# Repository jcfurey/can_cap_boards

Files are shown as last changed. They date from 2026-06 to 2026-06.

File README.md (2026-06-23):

# can_cap_boards

A repo to contain different PCBs with associated gerber files and SPICE sim docs.

The theme: small interior-mount boards that retire vintage multi-section
twist-lock "can" electrolytics in tube amps, replacing them with discrete,
individually serviceable modern radial caps.

> ⚠️ These boards carry **lethal B+ voltages** (400 V+). Discharge and meter
> every section to zero before handling. See each board's README.

## Boards

| Board | Amp | What it replaces | Status |
|---|-----|---|---|
| [`princeton_reverb_aa1164`](princeton_reverb_aa1164/) | Fender Princeton Reverb (AA1164) | 4-section can → 47/22/22/33 µF | design + BOM + SPICE + KiCad project (DRC-clean starter) + gerbers |

Each board folder contains its own `README.md` (design notes), `BOM.md`, an
illustrated `design_reference.html` (schematic + mechanical drawings), a `sim/`
directory with the SPICE supply model, and a `kicad/` directory with the KiCad
sources and `kicad/fab/` fabrication outputs (gerbers, drill, BOM, position).

## License

Apache-2.0 (see [`LICENSE`](LICENSE)).

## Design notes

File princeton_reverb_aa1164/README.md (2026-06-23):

# Princeton Reverb (AA1164) — Filter Cap Board

Interior-mount filter board that retires the original 4-section twist-lock "can"
electrolytic in the blackface Fender Princeton Reverb (AA1164) and close clones,
replacing it with discrete, individually serviceable, modern radial electrolytics.

Mounts inside the chassis among the existing circuitry, with the wire-entry holes
on the edge facing the fiber/eyelet board so the existing B+ wiring lands straight
across. The empty can knockout is covered separately (blanking plate / plug).

> 📄 **Illustrated design reference:** [`design_reference.html`](design_reference.html)
> — a single self-contained page with the schematic, board/mechanical drawings,
> 2-layer stackup, full BOM, and the design rules (R1–R6) as inline SVG. Open it
> in a browser; this README is the plain-text mirror.

> ⚠️ **High voltage.** B+ on the reservoir node sits near **420 VDC** in operation,
> and downstream nodes float up toward it during warm-up. Treat the whole board as
> lethal. Discharge and meter every section to zero before handling.

## Design goals

- Electrical drop-in for the stock can, but with individually replaceable caps
- Modern, high-quality radial electrolytics, **≥ 500 V**
- **Split** power / preamp-reverb grounds for low hum, star-tied
- Existing B+ wiring lands on the fiber-board-facing edge

## Filter values

| Node | Function | Value | Rating |
|---|---|---:|---|
| A (B+1) | Reservoir — 6V6 plates | 47 µF | 500 V, 105 °C |
| B (B+2) | Screens | 22 µF | 500 V, 105 °C |
| C (B+3) | PI / reverb driver | 22 µF | 500 V, 105 °C |
| D (B+4) | Preamp / reverb recovery | 33 µF | 500 V, 105 °C |

Anchor part: **Nichicon UCY2H470MHD** (47 µF / 500 V / 105 °C, 7.5 mm pitch,
16 × 40 mm). The 22 µF and 33 µF come from the same UCY family — confirm the exact
case suffix/size at the distributor.

Notes:
- Node A reservoir bumped to **47 µF** to firm up the low end (stays under the
  GZ34's ~60 µF input-cap limit).
- Node D laid out to accept up to **47 µF** so it stays retunable with an iron.
- Screens (B) and PI/reverb-driver (C) kept at stock 22 µF — extra capacitance
  there buys nothing audible.

## Grounding — split, star-tied

- **GND-PWR** — dirty returns: caps **A + B** and the bleeder
- **GND-PRE** — clean returns: caps **C + D**
- The two pours meet **only** at a single **star link (JP1)**, which is the single
  chassis tie.
  - Fit JP1 → one ground wire, single-point tie.
  - Omit JP1 → run GND-PWR and GND-PRE to their own amp ground buses for a true
    dual return.
- The rectifier center-tap belongs on the **power** side at the star, never on the
  preamp pour.
- Exactly **one** chassis connection either way — no loops.

If the reverb driver (node C) ever injects buzz, moving just that negative from
GND-PRE to GND-PWR turns this into a 3-way split — it's only a pour assignment.

## Layers & routing (2-layer)

- **Fiber-board face:** B+ traces + wire-entry pads. Traces **~2.5 mm** wide
  (robustness / HV margin, not current); teardrop the pad junctions.
- **Far face:** the two ground pours (GND-PWR / GND-PRE), each pulled back
  **≥ 2.5 mm** from B+.
- Same-layer clearance **≥ 2.5 mm** (3 mm where room allows). Opposite-layer
  isolation through 1.6 mm FR-4 is ample at ~420 V; optionally clear the pour in
  the shadow directly under B+ traces.

### KiCad tips

- GND-PWR and GND-PRE are **separate nets** joined by a **net-tie footprint** at
  JP1 — otherwise DRC flags them as a short.
- Put the four B+ nets in their own **net class** (clearance 2.5 mm, track ~2.5 mm)
  so DRC enforces creepage automatically.

## Mechanical

- Rectangular, ~**55–60 × 48 mm**, FR-4 2-layer, 1.6 mm, **1 oz** copper.
- Caps stand off the far face into open interior — verify ~40 mm depth clearance
  for the 47 µF (or lay caps down if it's tight).
- Mount on standoffs; **both mount holes isolated** from copper (or make exactly
  one the ground tie) to avoid a ground loop.

## Bleeder

2 × 100 kΩ 2 W (each ≥ 350 V working) in series (= 200 kΩ) across node A,
returning to GND-PWR. Dissipates ~0.9 W total (~0.45 W each), split across the
two so neither is stressed. Drains node A at power-off; downstream nodes drain
through the amp's dropping resistors while the board is connected. **Always meter
every section to zero before servicing.** Add a bleeder per node if you want each
section to self-drain when the board is pulled.

## Serviceability

- Existing B+ wires solder into labeled wire-entry pads — leave a little slack so
  the board lifts clear when you desolder.
- Silkscreen node labels (A/B+1 … D/B+4), values, and **polarity** at every pad.
- Want tool-free removal later? Add FASTON tabs in parallel with the wire pads.

## Fabrication

- Within both **JLCPCB** and **OSH Park** 2-layer design rules (the ≥ 2.5 mm
  spacing dwarfs their ~0.15 mm minimum; 1.6 mm wire-entry holes are routine).
- 1 oz copper is standard at both (meets the ≥ ½ oz target); 2 oz buys little here.
- OSH Park prices by area (~$5/in², 3 pcs, US-made ENIG) — keep it ~50 mm. Skip
  its 2 oz option: that's a thinner 0.8 mm board, and you want 1.6 mm rigidity.
- JLCPCB is a flat tier (5 pcs) up to 100 × 100 mm, so size is effectively free.
- If you ever convert to **solid-state rectification**, add inrush limiting
  (series resistance / soft-start) — 47 µF hits the PT harder on a cold start
  than the GZ34 does.

## Bill of materials

See [`BOM.md`](BOM.md) — the four filter caps, the bleeder, and the ground star
link (the inter-node dropping resistors stay on the amp's eyelet board).

## Simulation

ngspice model of the AA1164 supply (GZ34 + dropping network) lives in
[`sim/`](sim/) — see [`sim/README.md`](sim/README.md). It confirms the
47/22/22/33 µF set:

| Node | DC (idle) | Ripple (idle) | DC (full output) |
|---|---:|---:|---:|
| A (reservoir) | 420.7 V | 8.0 V pp | 403.5 V |
| B (screens) | 405.7 V | 0.41 V pp | 384.5 V |
| C (PI/reverb) | 358.7 V | 5.1 mV pp | 337.5 V |
| D (preamp) | 318.7 V | 0.1 mV pp | 297.5 V |

Node A sits at ~420 V as designed, the larger reservoir roughly thirds the
stock ripple, the hum-sensitive preamp nodes are filtered to ≤ mV, and the GZ34
sags node A ~17 V at full output (the expected blackface "compression").

## KiCad project

A KiCad 7 project lives in [`kicad/`](kicad/) — see [`kicad/README.md`](kicad/README.md).
Schematic + 2-layer board, **ERC/DRC-clean (0 errors)**, with the split-ground
star-tie and 2.5 mm HV creepage encoded as rules. Fabrication outputs (Gerbers,
drill, BOM, position) are in [`kicad/fab/`](kicad/fab/).

> These are an auto-generated **starting point**: electrically complete and
> rule-clean, but placement/mechanical fit must be verified in the GUI before
> fabbing (board outline, wire-entry positions vs your chassis, exact cap cases).

## Status

- [x] Electrical design (rev F)
- [x] Bill of materials
- [x] SPICE supply sim
- [x] KiCad schematic (ERC-clean)
- [x] KiCad layout (DRC-clean starter — refine mechanical fit in GUI)
- [x] Fabrication outputs (gerbers) — starter set, re-export after refining
- [ ] Built & tested

## License

Apache-2.0 (see repository `LICENSE`).

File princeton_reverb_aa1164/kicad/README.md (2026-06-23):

# KiCad project — AA1164 Filter Cap Board

KiCad 7 project for the Princeton Reverb (AA1164) filter-cap board. This is a
**starting point**: electrically complete, ERC/DRC-clean, with the HV creepage
and split-ground rules baked in — but the placement and mechanical fit still
want a pass in the GUI before you fab it.

> Built/validated with KiCad **7.0.11**. KiCad 9 opens it fine (it will offer to
> upgrade the files). The two generator scripts below are the scaffolding used
> to create it; the `.kicad_sch` / `.kicad_pcb` are now the editable sources.

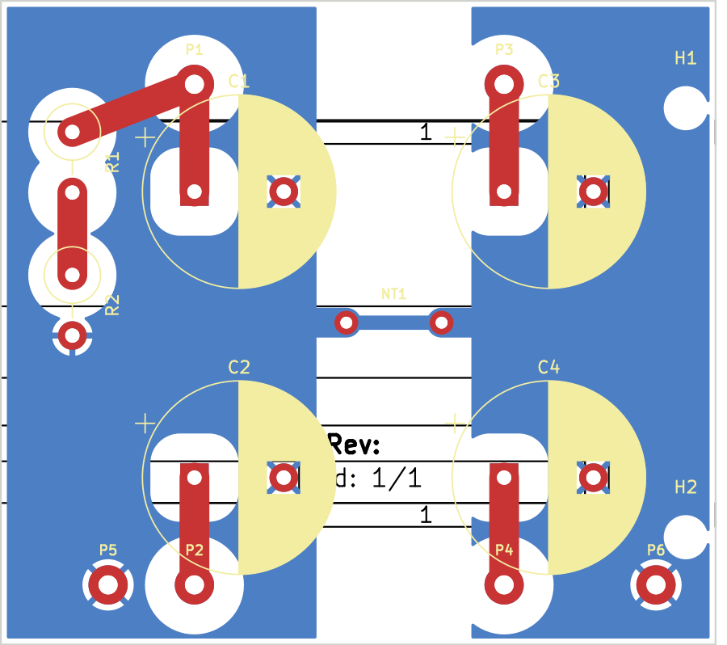
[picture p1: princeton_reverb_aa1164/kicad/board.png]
board


*B.Cu split ground pours (blue) joined only at the NT1 star-tie; F.Cu B+ traces
(red); 2×2 caps with each B+ wire-entry beside its cap; bleeder R1/R2 top-left;
mounting holes right. The wide white rings are the 2.5 mm HV anti-pads in the
pour.*

## Files

| File | What |
|---|---|
| `princeton_reverb_aa1164.kicad_pro` | Project (net classes: 2.5 mm clearance / 2.5 mm tracks) |
| `princeton_reverb_aa1164.kicad_sch` | Schematic — 4 caps, bleeder, 6 wire-entry pads, star-tie, 2 mounts |
| `princeton_reverb_aa1164.kicad_pcb` | 2-layer board: B+ on F.Cu, split GND pours on B.Cu |
| `wire_entry.pretty/` | Custom footprints: `WireEntry_BPlus`, `WireEntry_GND` (1.6 mm hole / 3.3 mm pad), `StarTie_8mm` (net-tie) |
| `fp-lib-table` / `sym-lib-table` | Register the project footprint library |
| `generate_sch.py` / `generate_pcb.py` | The scripts that generated the above (kiutils + pcbnew) |
| `fab/` | Fabrication outputs — see `fab/` |
| `drc.rpt` | Saved DRC run (0 errors) |

## Nets & rules

- B+ nodes are **separate nets** `HV_A..HV_D` (each = wire-entry pad + cap "+",
  plus the bleeder on A) — they only join *outside* the board, in the amp.
- `BLEED_MID` is the junction of the two series bleeder resistors.
- Grounds are **two nets** `GND-PWR` (caps A·B + bleeder) and `GND-PRE`
  (caps C·D), joined **only** at the `NT1` star-tie (a net-tie footprint, so DRC
  permits the single intentional short). Omit/DNP NT1 to run dual returns.
- Board-wide clearance is **2.5 mm** and default track width **2.5 mm** — every
  net here is HV or ground, so one rule enforces the creepage spec everywhere.

## Validation

- **Connectivity** verified by netlist export (matches the intended net map).
- **DRC: 0 errors.** The 12 remaining items are warnings only:
  - `lib_footprint_issues` (8) — headless DRC has no global footprint-library
    table; these disappear in the GUI.
  - `silk_over_copper` (4) — cosmetic cap-outline silk over mask openings.
- KiCad 7's `kicad-cli` has no `erc`/`drc` subcommand (KiCad 8+), so ERC/DRC were
  run via the netlist export and `pcbnew.WriteDRCReport`. **Re-run ERC and DRC in
  your GUI** as a final check after any edits.

## Refine before fabbing

This was placed/routed *blind to the real chassis*. In the GUI:

1. **Verify mechanical fit** — board outline (~60 × 54 mm here vs the ~55–60 × 48
   target), the wire-entry positions against your fiber board, and cap body
   height clearance into the interior.
2. Optionally **regroup the wire-entry pads into one edge row** (they're placed
   next to each cap here for short, clean B+ traces).
3. Confirm the **cap footprints** — all four use `CP_Radial_D16.0mm_P7.50mm`
   (sized for the 47 µF); the 22/33 µF bodies are smaller, so swap to the right
   case once you pick exact parts.
4. Confirm the **bleeder** uses a vertical 2 W footprint that matches your
   resistors, and that the **star-tie** location suits your single chassis tie.
5. Re-run ERC + DRC.

## Regenerating

```sh
pip install kiutils
python3 generate_sch.py      # writes the .kicad_sch
python3 generate_pcb.py      # writes the .kicad_pcb, fills zones, runs DRC
```
Regenerating overwrites GUI edits — once you start editing in KiCad, treat the
`.kicad_sch`/`.kicad_pcb` as the sources and retire the scripts.

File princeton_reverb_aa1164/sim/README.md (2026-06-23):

# AA1164 Power-Supply SPICE Sim

ngspice model of the blackface Princeton Reverb (AA1164) high-voltage supply,
used to verify **ripple at each B+ node** and **DC sag** with this board's
filter set (A/B/C/D = **47 / 22 / 22 / 33 µF**) feeding the stock dropping
network.

## Files

| File | Purpose |
|---|---|
| `aa1164_psu.cir` | ngspice deck — rectifier + filter chain + loads, with a `.control` block that prints DC and ripple per node |
| `plot_ripple.py` | Runs the deck and renders `aa1164_psu_ripple.png` (steady-state ripple per node) |
| `aa1164_psu_ripple.png` | Committed plot of the idle-load result |
| `results.txt` | Saved console output of the idle-load run |

The raw transient dump (`aa1164_psu_nodes.dat`, ~30 MB) is regenerated on every
run and is **git-ignored** — don't commit it.

## Running

```sh
ngspice -b aa1164_psu.cir        # prints the DC/ripple table
python3 plot_ripple.py           # regenerates aa1164_psu_ripple.png
```

Requires `ngspice`, plus `numpy` + `matplotlib` for the plot.

## Circuit model

```
   330-0-330 VAC          GZ34 (2 plates)
   centre-tapped     ┌──►|──┐
   secondary    ─────┤      ├──┬─── A ──[1k]── B ──[4.7k]── C ──[10k]── D
   (CT = gnd)   ─────┤      │  │       │            │            │       │
                     └──►|──┘ 47µF   22µF         22µF         33µF    (each
                               │       │            │            │      to gnd)
                             200k      ▼            ▼            ▼       ▼
                            bleeder  screens   PI/reverb     preamp /
                                     (6V6)      driver      reverb recov
                       6V6 plates ◄──┘
```

- **Rectifier:** GZ34/5AR4 full-wave centre-tap, approximated by a solid-state
  diode with series resistance (`RS=60` in the `.model` + 75 Ω winding R per
  half). This reproduces forward drop and **sag** well, but **not** the GZ34's
  slow indirectly-heated warm-up — that's deliberate; we want steady-state
  numbers, not the turn-on transient (which is exactly why a tube rectifier is
  used: it spares the caps the cold-start surge).
- **Loads** are modelled as DC current sinks per node (tubes ≈ constant-current
  over a line cycle). Idle defaults: A 45 mA, B 5 mA, C 6 mA, D 4 mA (~60 mA
  HT total, typical for a Princeton Reverb).
- **Settling:** the deck runs to **8 s**. The downstream RC poles are slow
  (node D ≈ `RCD·CD` = 10 k × 33 µF ≈ 0.33 s); shorter runs leave the chain
  un-settled and report bogus DC/ripple on C and D. Ripple is measured over the
  last 50 ms (6 × 120 Hz cycles).

> Component values are the **standard AA1164** schematic values (PT secondary,
> dropping resistors, loads). Verify against *your* chassis before trusting the
> absolute volts — especially the transformer secondary, which varies with mains
> voltage and PT model. The **ripple** conclusions are robust to small value
> errors; the **DC** levels scale with whatever your secondary actually is.

## Results

### Idle (~60 mA HT) — the committed plot

| Node | Cap | DC (V) | Ripple (pk-pk) |
|---|-----|---:|---:|
| A — reservoir / 6V6 plates | 47 µF | **420.7** | **8.0 V** |
| B — screens | 22 µF | 405.7 | 0.41 V |
| C — PI / reverb driver | 22 µF | 358.7 | 5.1 mV |
| D — preamp / reverb recovery | 33 µF | 318.7 | 0.1 mV |

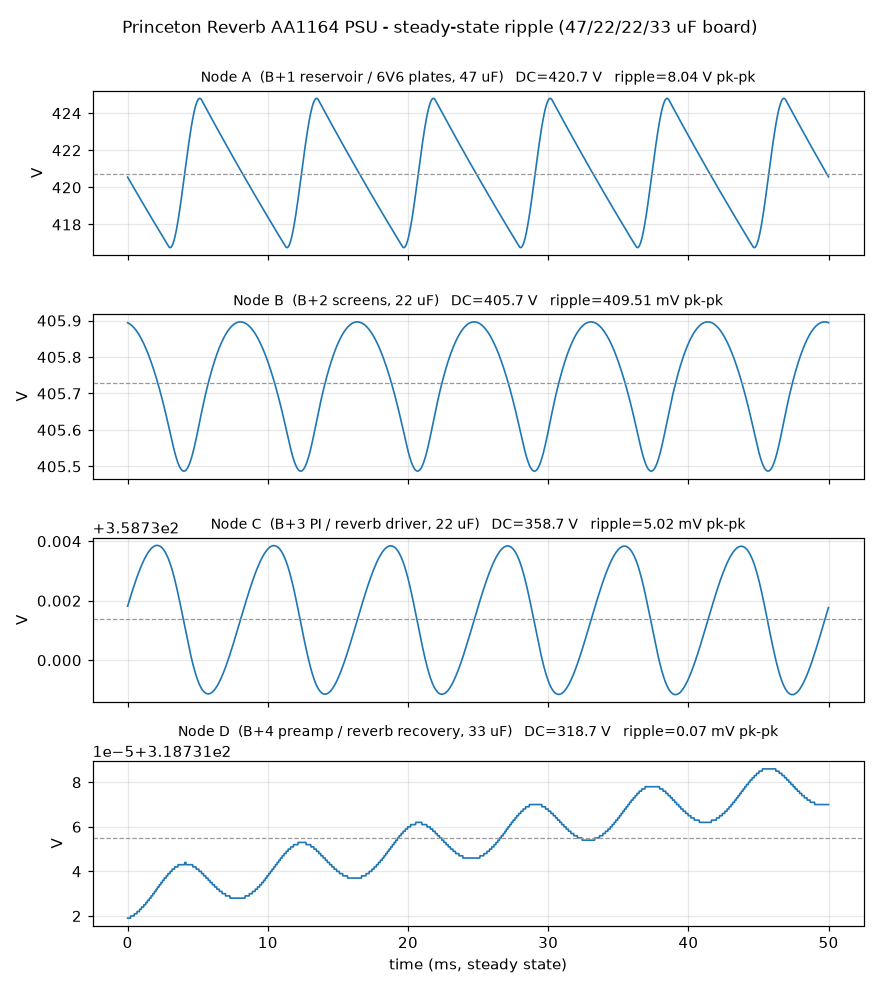
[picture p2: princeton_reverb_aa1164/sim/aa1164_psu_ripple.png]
ripple


### Full output (plates ~80 mA, screens ~9 mA) — sag

| Node | DC (V) | Δ vs idle | Ripple (pk-pk) |
|---|---:|---:|---:|
| A | 403.5 | −17 V | 12.3 V |
| B | 384.5 | −21 V | 0.63 V |
| C | 337.5 | −21 V | 7.9 mV |
| D | 297.5 | −21 V | 0.1 mV |

Reproduce by editing the `.param IA`/`IB` lines near the bottom of the deck.

## What it tells us

- **Node A ≈ 420 V idle**, matching the README's "near 420 V" — the board and
  bleeder rating margin (500 V caps, 200 kΩ bleeder) are correct.
- **Reservoir ripple ~8 V at idle, ~12 V at full output.** That's normal for a
  Princeton-class amp; bumping A from the stock 16 µF to **47 µF** roughly thirds
  the reservoir ripple versus stock, firming the low end.
- **Hum-sensitive nodes are quiet:** screens already at 0.4 V, and the
  PI/preamp nodes (C, D) are filtered to **single-digit mV or below** — well
  under the threshold for audible hum at the preamp.
- **Sag:** node A drops ~17 V plate-to-idle under full output — the GZ34
  "compression" that gives these amps their feel. The larger reservoir trades a
  little of that softness for tighter lows; if you want more sag, that's the
  knob (reservoir µF), not the downstream caps.
- Downstream cap values (B/C/D) buy **no audible ripple improvement** beyond
  stock — consistent with keeping B and C at 22 µF; D's 33 µF is for headroom/
  retunability, not hum.

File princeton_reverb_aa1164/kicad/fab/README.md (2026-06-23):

# Fabrication outputs — AA1164 Filter Cap Board

Generated from `../princeton_reverb_aa1164.kicad_pcb` with `kicad-cli` (KiCad 7).
**Regenerated artifacts** — re-export after any board edit.

> ⚠️ This is a *starting* layout — verify mechanical fit and re-run DRC in the
> KiCad GUI before actually ordering. See `../README.md`.

## Contents

| File | What |
|---|---|
| `princeton_reverb_aa1164-gerbers.zip` | All Gerbers + drill, zipped for upload |
| `gerbers/*.gbr` | RS-274X Gerbers (F.Cu, B.Cu, F/B silkscreen, F/B mask, Edge.Cuts) |
| `gerbers/*.drl` | Excellon drill (absolute origin, mm) + `-drl_map.gbr` map |
| `gerbers/*.gbrjob` | Gerber job file |
| `princeton_reverb_aa1164-pos.csv` | Pick-and-place positions (both sides, mm) |
| `princeton_reverb_aa1164-bom.csv` | Grouped BOM (qty / value / footprint / refs) |

All parts are **through-hole**, so the pos/BOM files are mostly for reference,
not automated assembly.

## Suggested fab settings

- 2-layer, **FR-4 1.6 mm**, **1 oz** copper, HASL or ENIG.
- Min track/space on this board is **2.5 mm** — far inside any fab's limits.
- Smallest drill is **1.0 mm** (net-tie / mounting-hole-adjacent); finished
  wire-entry holes are **1.6 mm**.
- Well within both **JLCPCB** and **OSH Park** 2-layer rules (see the board
  `README.md` for the cost trade-off).

## Re-exporting

```sh
cd ..
kicad-cli pcb export gerbers --no-protel-ext \
  --layers "F.Cu,B.Cu,F.SilkS,B.SilkS,F.Mask,B.Mask,Edge.Cuts" -o fab/gerbers/ princeton_reverb_aa1164.kicad_pcb
kicad-cli pcb export drill --format excellon --drill-origin absolute \
  --generate-map --map-format gerberx2 -o fab/gerbers/ princeton_reverb_aa1164.kicad_pcb
kicad-cli pcb export pos --format csv --units mm --side both \
  -o fab/princeton_reverb_aa1164-pos.csv princeton_reverb_aa1164.kicad_pcb
```

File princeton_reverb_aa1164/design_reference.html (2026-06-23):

Filter cap board · drop-in can replacement

# Princeton Reverb AA1164

Modern radial-electrolytic board to retire the original twist-lock can — an interior board with discrete, high-quality caps you can swap with an iron, and the existing B+ wiring landing on the fiber-board edge.

Node A · B+1

47µF

Node B · B+2

22µF

Node C · B+3

22µF

Node D · B+4

33µF

Rating

500V · 105°C

⚠ HV

B+ on the reservoir node sits near 420 VDC in operation, and downstream nodes float up toward it during warm-up. Treat the whole board as lethal. Discharge every section before touching it — the on-board bleeder only drains node A while the board is connected to the amp.

01

## What this board does

Four independent B+ nodes, each filtered by its own radial electrolytic. The dirty power-supply returns (reservoir + screens) sit on their own ground, separate from the clean preamp/reverb returns, joined at a single star tie — that keeps the rectifier's charging-pulse currents out of the preamp's ground reference for lower hum, while still presenting one ground to the chassis. The reservoir is bumped to 47µF to firm up the low end (within the GZ34's ~60µF input limit); the preamp/reverb node is set to 33µF for a touch of headroom on an already-quiet amp, on a footprint that will still accept 47µF later. Screens and the PI/reverb-driver node stay at the stock 22µF, where extra capacitance buys nothing audible.

02

## Schematic

Two ground groups — GND-PWR for the dirty returns (caps A·B + bleeder), GND-PRE for the clean preamp/reverb returns (caps C·D) — meeting at one star link. Fit the link for a single chassis tie; omit it and run each group to its own ground bus for a true split return. Node-to-stage roles follow the AA1164 layout — verify against your actual wiring on a clone.

03

## Bill of materials

Ref | Qty | Value | Rating | Part / footprint | Notes
C1 | 1 | 47µF | 500V 105°C | Nichicon UCY2H470MHDradial, 7.5mm pitch, ~16 × 40mm | Reservoir (node A). Tightens low end.
C2 | 1 | 22µF | 500V 105°C | Nichicon UCY2H220M__same family — confirm case suffix/size | Screens (node B).
C3 | 1 | 22µF | 500V 105°C | Nichicon UCY2H220M__same family — confirm case suffix/size | PI / reverb driver (node C).
C4 | 1 | 33µF | 500V 105°C | Nichicon UCY2H330M__confirm suffix · lay out pad for 47µF body | Preamp / reverb recovery (node D). retunable 22–47µF
R1, R2 | 2 | 100kΩ | 2W, ≥350V | metal-oxide / flameproof, axial | Series across node A = 200k bleeder (~0.9W total, split).
P1–P4 | 4 | — | — | wire-entry PTH, ~1.6mm finishedno purchased part — board feature | Existing B+ wires poke up through the knockout and solder in.
GND-PWR / GND-PRE | 2 | — | — | 2 × wire-entry PTH + chassis lug | Separate dirty (A·B) and clean (C·D) returns; meet at the star.
JP1 | 1 | — | 0Ω / link | solder bridge or wire link | Star: fit = one chassis tie; omit = dual return to amp ground buses.
PCB | 1 | — | — | FR-4, 2-layer, 1.6mm, 1oz Curectangular ~50–60mm (2×2) | 1oz meets ≥½oz; ≥2.5mm HV creepage; optional slots + conformal coat.

04

## Board & mechanical layout

This mounts inside the chassis among the existing circuitry, not over the knockout. The wire-entry holes sit in a row along one edge — the edge facing your fiber board — so the existing B+ wires land straight across with no wrapping. Caps stand off the opposite face; mount on standoffs with both holes isolated. The empty can hole is best capped separately with a simple blanking plate or plug.

Interior mount: the board sits among the circuitry with its wire-entry edge toward the fiber board, so the existing B+ wires cross straight over and solder on that face. Caps stand off the far face (which carries the ground plane) into open interior space. Stand it off the chassis on isolated mount holes; cap the empty can hole separately.

05

## Layers & routing

Two copper layers, split by job. The side facing your fiber board carries every B+ trace and the wire-entry pads, so the existing wires land and solder on the face they come from — no wrapping around the board. The opposite side, under the caps and facing away from the fiber board, carries the two ground pours — power and preamp/reverb — split for low hum and joined only at the star.

Cross-section through one cap and its wire-entry pad. B+ lives on the fiber-board side as fat, short traces; ground is a plane on the cap side. Opposite-layer isolation through 1.6mm FR-4 is ample at 420V, so B+ riding over the plane is fine — the spec that bites is same-layer surface clearance.

### B+ traces

Fat and short on the fiber-board side — ~2.5mm (100 mil) wide. The current is tiny; the width is for HV robustness and handling, not ampacity. Teardrop the pad junctions and round corners to resist etch defects and cracking.

### Ground pours

Two pours on the cap side — GND-PWR under caps A·B, GND-PRE under caps C·D — each pulled back ≥2.5mm from B+. They meet only at the star link (one chassis tie), which keeps the rectifier's charging-pulse current off the preamp reference.

### Clearances

Same-layer surface: ≥2.5mm B+↔B+ and B+↔ground (3mm where room allows). Opposite-layer through 1.6mm FR-4 is fine at 420V — for extra margin, clear the plane in the shadow directly beneath the B+ traces.

### Holes & mounting

Wire-entry ~1.6mm hole / ~3.3mm pad — a generous ring for hand soldering. Stitch the plane to the GND pad with a few vias. Isolate both mount holes from copper (or make exactly one the ground tie) so two chassis screws can't form a ground loop.

06

## Design rules to hold the line on

### R1Creepage & clearance

Adjacent nodes can differ by 100–200V and the bus rides near 420V. Keep ≥2.5mm (0.1") bare between any two HV nodes and from HV to the ground pour / chassis metal — more if the board allows. A routed slot between nodes and/or conformal coat buys margin. IPC-2221 is the formal reference.

### R2Grounding

Two pours: GND-PWR for the dirty returns (caps A·B + bleeder), GND-PRE for the clean preamp/reverb returns (caps C·D). They meet only at the star link — the single chassis tie. Fit the link for one ground wire, or omit it and run each pour to its own amp ground bus for a true split return. Either way, exactly one chassis connection; the rectifier center-tap lands on the power side at the star, never on the preamp pour.

### R3Bleeder & service

The 200k bleeder drains node A when the amp is off. Downstream nodes drain through the amp's dropping resistors only while the board is connected. Always meter every section to zero before servicing; add a bleeder per node if you want each section to self-drain when the board is pulled.

### R4Serviceability

Existing B+ wires solder into labeled wire-entry pads — leave a little slack so the board lifts clear when you desolder. Silkscreen node labels (A/B+1 … D/B+4), values, and polarity at every pad. Lay out C4 to accept up to 47µF so node D stays retunable with an iron. Want tool-free removal later? Add FASTON tabs in parallel with the wire pads.

### R6Fab & copper

Well inside both JLCPCB and OSH Park 2-layer rules — our ≥2.5mm spacing dwarfs their ~0.15mm minimum, and 1.6mm wire-entry holes are routine. Standard 1oz copper at either fab clears your ½oz floor; ripple currents here are small, so 2oz buys little. OSH Park prices by area (~$5/in² for 3, US-made, ENIG), so keep it ~50mm; JLC is a flat tier up to 100×100mm for 5 pcs, so size is effectively free and you can spread out. Skip OSH Park's 2oz option — it's a thinner 0.8mm board, and you want 1.6mm rigidity for a cover.

### R5Rectifier headroom

47µF reservoir is inside the GZ34's ~60µF input-cap limit — fine. If you ever convert to solid-state rectification, add inrush limiting (series resistance / soft-start), since 47µF hits the PT harder on a cold start.

Princeton Reverb AA1164 — filter cap board · rev F · 47/22/22/33 µF @ 500V · split grounds (power | preamp/reverb) · interior mount · 1oz Cu

Reference design and starting point, not a finished manufacturing package. Verify node-to-stage mapping, the actual knockout/mount style, and final cap dimensions against your specific chassis before committing the board outline.

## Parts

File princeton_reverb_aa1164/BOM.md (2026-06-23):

# BOM — Princeton Reverb (AA1164) Filter Cap Board

Rev F electrical design. Quantities are **per board**.

> **Scope:** only the parts that live *on this board* — the four filter caps,
> the bleeder, and the ground star link. The dropping resistors (1 k / 4.7 k /
> 10 k) between nodes stay on the amp's eyelet board and are **not** part of this
> BOM; they appear in the SPICE model (`sim/`) only to reproduce the node
> voltages.

## Filter capacitors

All electrolytics: aluminium, radial, **≥ 500 V**, **105 °C**, 7.5 mm pitch.
Anchor family: **Nichicon UCY** (voltage code `2H` = 500 V, `M` = ±20 %).
Confirm the exact case-size suffix at the distributor — it varies with µF.

| Ref | Node | Value | Rating | Suggested P/N | Qty |
|-----|---|---:|---|---|:---:|
| C1 | A — B+1 reservoir / 6V6 plates | 47 µF | 500 V 105 °C | Nichicon UCY2H470MHD (16 × 40 mm) | 1 |
| C2 | B — B+2 screens | 22 µF | 500 V 105 °C | Nichicon UCY2H220M&lt;suffix&gt; | 1 |
| C3 | C — B+3 PI / reverb driver | 22 µF | 500 V 105 °C | Nichicon UCY2H220M&lt;suffix&gt; | 1 |
| C4 | D — B+4 preamp / reverb recovery | 33 µF | 500 V 105 °C | Nichicon UCY2H330M&lt;suffix&gt; | 1 |

- C1 bumped to 47 µF to firm the low end (stays under the GZ34's ~60 µF
  input-cap limit).
- C4 footprint laid out to accept **up to 47 µF** so node D stays retunable.
- 22 µF on C2/C3 is the stock value — more capacitance there buys nothing
  audible (confirmed by `sim/`: C/D ripple is already single-digit mV).

## Bleeder

| Ref | Value | Rating | Notes | Qty |
|-----|---:|---|---|:---:|
| R1, R2 | 100 kΩ | 2 W, ≥ 350 V | In series = 200 kΩ across node A → GND-PWR | 2 |

Metal-oxide / flameproof, axial. ~0.9 W total across node A, split (~0.45 W
each). Drains node A at power-off; downstream nodes drain through the amp's
dropping resistors while the board is connected. **Still meter every section to
zero before servicing.**

## Grounding / hardware

These are **board features**, not purchased parts (except the standoffs) —
listed so nothing is missed at layout.

| Ref | Item | Notes | Qty |
|-----|---|---|:---:|
| P1–P4 | B+ wire-entry pads (PTH) | ~1.6 mm finished hole / ~3.3 mm pad, in a row on the fiber-board-facing edge; existing B+ wires poke up and solder in. | 4 |
| GND-PWR, GND-PRE | Ground wire-entry pads (PTH) + chassis lug | Separate dirty (A·B) and clean (C·D) returns; meet at the star. | 2 |
| JP1 | Star link (net-tie) | Joins GND-PWR ↔ GND-PRE at one point. Fit a wire/0 Ω link for single-point tie; omit to run dual returns to the amp's own buses. | 0–1 |
| — | Mounting standoffs + screws | Both mount holes isolated from copper (or make exactly one the ground tie) to avoid a ground loop. | 2 ea |

## Bare board

| Item | Spec |
|---|---|
| PCB | FR-4, 2-layer, 1.6 mm, 1 oz Cu, ~55–60 × 48 mm. Within JLCPCB & OSH Park 2-layer rules. |

---

*Part numbers are suggestions, not the only valid choice — any radial
electrolytic at ≥ 500 V / 105 °C in the right µF and a 7.5 mm pitch / ≤ 16 mm
diameter case will fit. Verify the case suffix and physical size against the
footprint before ordering.*

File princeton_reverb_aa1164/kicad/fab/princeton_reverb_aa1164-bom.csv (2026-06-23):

Qty | Value | Footprint | References
1 | 47µF | Capacitor_THT:CP_Radial_D16.0mm_P7.50mm | C1
2 | 22µF | Capacitor_THT:CP_Radial_D16.0mm_P7.50mm | C2,C3
1 | 33µF | Capacitor_THT:CP_Radial_D16.0mm_P7.50mm | C4
2 | MountingHole | MountingHole:MountingHole_3.2mm_M3 | H1,H2
1 | STAR | wire_entry:StarTie_8mm | NT1
1 | B+1_A | wire_entry:WireEntry_BPlus | P1
1 | B+2_B | wire_entry:WireEntry_BPlus | P2
1 | B+3_C | wire_entry:WireEntry_BPlus | P3
1 | B+4_D | wire_entry:WireEntry_BPlus | P4
1 | GND-PWR | wire_entry:WireEntry_GND | P5
1 | GND-PRE | wire_entry:WireEntry_GND | P6
2 | 100k | Resistor_THT:R_Axial_DIN0414_L11.9mm_D4.5mm_P5.08mm_Vertical | R1,R2

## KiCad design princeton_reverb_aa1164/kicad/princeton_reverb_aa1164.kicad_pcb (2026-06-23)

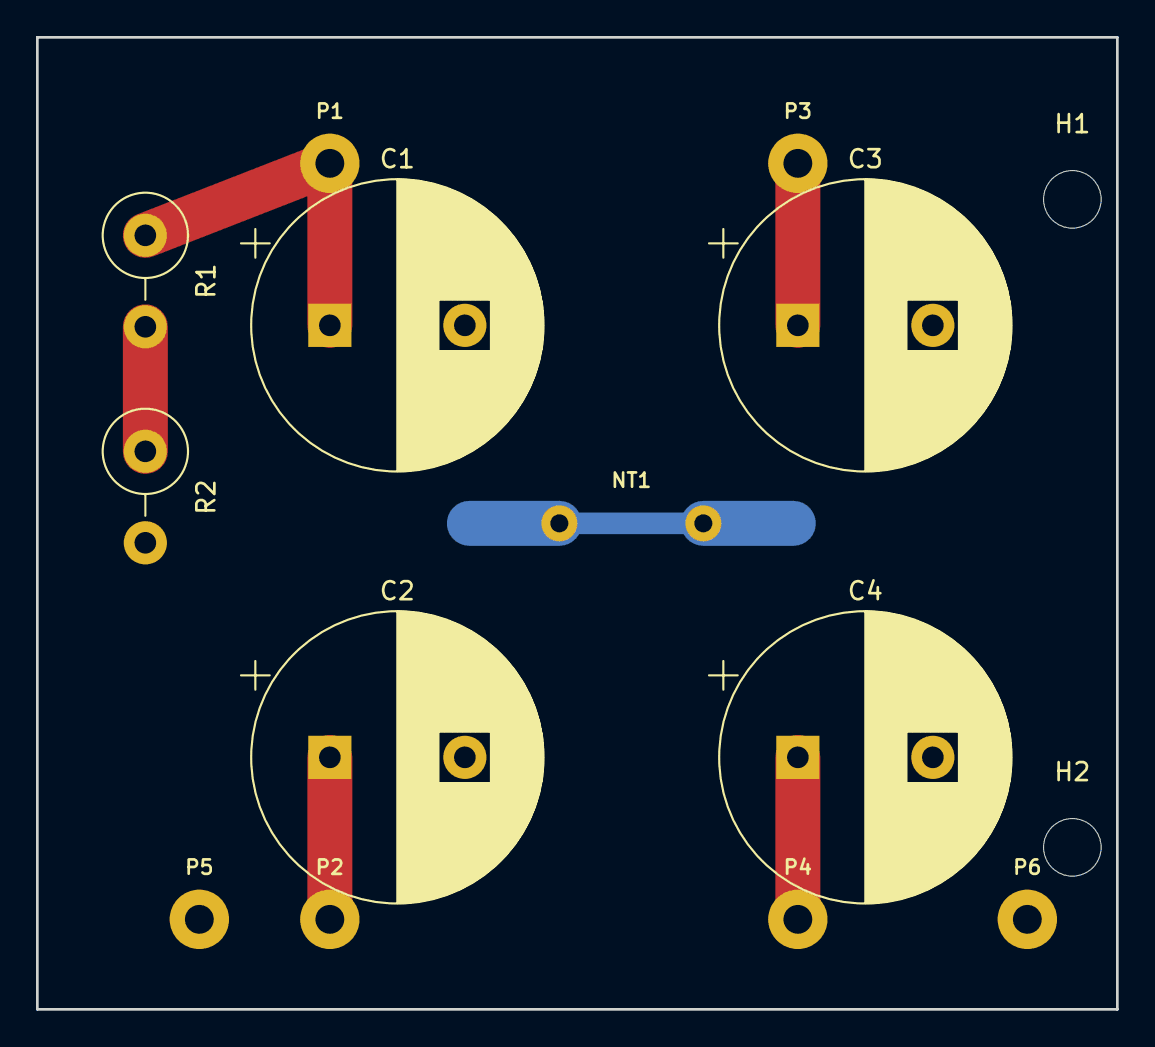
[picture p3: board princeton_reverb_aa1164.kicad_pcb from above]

Board: 2 copper layers, 60.0 x 54.0 mm, 15 parts (0 on the bottom side), 7 nets.

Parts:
C1: 47uF; CP_Radial_D16.0mm_P7.50mm
C2, C3: 22uF; CP_Radial_D16.0mm_P7.50mm
C4: 33uF; CP_Radial_D16.0mm_P7.50mm
H1, H2: MountingHole_3.2mm_M3
NT1: STAR; StarTie_8mm
P1: B+1_A; WireEntry_BPlus
P2: B+2_B; WireEntry_BPlus
P3: B+3_C; WireEntry_BPlus
P4: B+4_D; WireEntry_BPlus
P5: GND-PWR; WireEntry_GND
P6: GND-PRE; WireEntry_GND
R1, R2: 100k; R_Axial_DIN0414_L11.9mm_D4.5mm_P5.08mm_Vertical

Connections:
BLEED_MID: R1.2, R2.1
GND-PRE: C3.2, C4.2, NT1.2, P6.1
GND-PWR: C1.2, C2.2, NT1.1, P5.1, R2.2
HV_A: C1.1, P1.1, R1.1
HV_B: C2.1, P2.1
HV_C: C3.1, P3.1
HV_D: C4.1, P4.1

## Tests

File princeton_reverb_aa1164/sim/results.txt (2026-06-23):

Using SPARSE 1.3 as Direct Linear Solver

Note: No compatibility mode selected!

Circuit: AA1164 Princeton Reverb PSU - 47/22/22/33uF filter board

Doing analysis at TEMP = 27.000000 and TNOM = 27.000000

Using transient initial conditions
 Reference value :  1.32798e+00
 Reference value :  2.61384e+00
 Reference value :  3.93728e+00
 Reference value :  5.36801e+00
 Reference value :  6.75679e+00
No. of Data Rows : 408349
a_dc                =  4.207315e+02 from=  7.950000e+00 to=  8.000000e+00
a_min               =  4.167539e+02 at=  7.953048e+00
a_max               =  4.247978e+02 at=  7.963488e+00
b_dc                =  4.057315e+02 from=  7.950000e+00 to=  8.000000e+00
b_min               =  4.054870e+02 at=  7.987366e+00
b_max               =  4.058965e+02 at=  7.999726e+00
c_dc                =  3.587314e+02 from=  7.950000e+00 to=  8.000000e+00
c_min               =  3.587288e+02 at=  7.997426e+00
c_max               =  3.587339e+02 at=  7.952110e+00
d_dc                =  3.187311e+02 from=  7.950000e+00 to=  8.000000e+00
d_min               =  3.187310e+02 at=  7.950010e+00
d_max               =  3.187311e+02 at=  7.995752e+00

===================================================================
AA1164 PSU steady-state  (last 50 ms @ 8 s, 120 Hz ripple)
===================================================================
Node  Cap     DC (V)     ripple pk-pk (mV)
-------------------------------------------------------------------
A     47uF    420.732      8043.9
B     22uF    405.731      409.5
C     22uF    358.731      5.1
D     33uF    318.731      0.1
===================================================================
Note: Simulation executed from .control section

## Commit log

2026-06-23 princeton_reverb_aa1164: add SPICE supply sim, BOM, and docs
    Flesh out the Princeton Reverb (AA1164) filter-cap board folder beyond the
    rev-F design notes:
    - sim/: runnable ngspice model of the AA1164 supply (GZ34 full-wave rect +
    stock dropping network) verifying the 47/22/22/33 uF set. Confirms node A
    ~420 V with ~8 V reservoir ripple, hum-sensitive preamp nodes filtered to
    <= mV, and ~17 V GZ34 sag at full output. Includes plot_ripple.py and a
    committed ripple plot. Runs to 8 s so the slow downstream RC tail settles.
    - BOM.md: per-board parts (4 filter caps, 200k bleeder, ground star link).
    - Update board + top-level README with results, BOM link, and board index.
    - gitignore the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
2026-06-23 princeton_reverb_aa1164: add illustrated HTML design reference
    Add the self-contained design_reference.html (schematic, board/mechanical
    drawings, 2-layer stackup, BOM, and R1-R6 design rules as inline SVG) and
    reconcile the markdown docs with the extra specifics it carries:
    - README: link the design reference; add bleeder voltage/power rating, a
    serviceability section (FASTON option, polarity silkscreen), OSH Park 2oz
    caveat, and the solid-state-rectifier inrush note.
    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
2026-06-23 princeton_reverb_aa1164: add KiCad project, layout, and gerbers
    Start the actual EDA work for the filter-cap board (previously only design
    docs/SPICE existed; the "schematic"/"layout" were illustrative SVG only).
    KiCad 7 project under kicad/:
    - Schematic (.kicad_sch): 4 filter caps, series bleeder, 6 wire-entry pads,
    split grounds (GND-PWR/GND-PRE) joined at an NT1 star-tie, 2 mounts.
    Connectivity verified by netlist export.
    - 2-layer board (.kicad_pcb): B+ traces on F.Cu, split ground pours on B.Cu
    joined only at the net-tie; board-wide 2.5 mm clearance/track enforces the
    HV creepage spec. DRC: 0 errors (12 benign warnings: headless lib-table +
    cosmetic silk).
    - Custom footprints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
    [princeton_reverb_aa1164-bom.csv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]
